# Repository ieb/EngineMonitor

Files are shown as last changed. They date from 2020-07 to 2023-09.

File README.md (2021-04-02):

# EngineMonitor

An engine monitor using a ESP-WROOM-32 board from ebay. It senses 1wire temperature, i2c pressure and temperature (BMP280), and has 2 digial inputs and 4 analogue inputs (ADS1115) for monitoring a typical marine diesel engine. In addition there is a JDY-40 serial RF interface for polling remote sensors.

It emits NMEA2000 messages to a NMEA200 bus, with configuration over Classic Bluetooth serial, saved to flash.

It supports PGN PGN127488 (rapid engine), PGN127489 (engine data), PGN130312 (various temperatures), PGN127508 (battery status), PGN127513 (battery configuration).

Sensors include:

* RPM from W+ terminal of alternator.
* Coolant Temperature
* Oil Pressure
* Fuel Level
* Alternator Voltage
* Alternator Temperature
* Exhaust Temperature
* Engine Room Temperature
* Environment Temperature and Pressure

Other values for the PGNs above are based on interpolation, best guess, fake, where possible. Target engine is a D2-40F, so the code is setup for that engines curves and prop. Most parameters can be changed over the Bluetooth serial CLI.

## RF

Over RF (TBD), Devices based on Arduino Pro Mini, JDY-40, ADS1115 (Arduino ADC not flexible enough). JDY-40s provide a serial 128 RF bands. In each band devices with the same RFID (WirelessID 2bytes) and DVID (Device ID 2bytes). Both the transmitter and reciever channel, RFID and DeviceID must match for packets to be transfered. These are set by AT commands to switch the trancever into that mode. The device will ignore packets that dont match and wont recieve packets that are on a different channel.

JDY-40s were chosen becuase they have a simple serial interface and are relativey low power. BT Classic would have been an alternative but requires pairing and wont work in a mesh and doesnt have the range (top of mast for some sensors). BLE, is just too complex to be bothered with. ZigBee modules are too expensive. NRF24L01+ could have been used, however the interface is SPI. If the JDY-40 cant operate in a mesh then they may need to be replaced with NRF24L01+. For the moment JDY-40 seems the simplest approach, however there is no deal on the JDY-40 RF protocol whereas the NRF24L01+ is detailed https://www.sparkfun.com/datasheets/Components/SMD/nRF24L01Pluss_Preliminary_Product_Specification_v1_0.pdf and has a TCP like RF protocol, and allows upto 6 transmitters to send to a single reciever over parallel data pipes. 

### Communication pattern.

The sensors involved need to provide data periodically, eg every 10s rather than stream continuously at 5Hz. So the simplest mechanism is to use the RFID ID/DeviceID setting in the JDY40. Each node is allocated a ID. On start it waits for a query. The base cycles through each ID requesting data and waiting for a set period for a response before moving to the next device. No blocking operations with communications going via the main loop.

### Protocol

Single line terminated by a NL. Fields comma seperated with the last field being a hex encoded crc16. 
    
      deviceid,datatype,field1,field2,...,fieldn,checksumNL

      device id is the id of the device, 0-255, hex
      datatype defines the fields, 0-255, hex
      field1..n the fields, text formatted.
      checksum a hex crc16 of the whole line excluding , before the checksum.
      NL a new line character.

* Engine Battery voltage, current, temperature, configuration
* Service Battery voltage, current, temperature, configuration

## PCB

The PCB handles power and signal cleaning. 
It is single sided and can easilly be created using basic laser printer+CuCl etching at home, or using a CNC PCB Milling machine (FlatCAM+Candle). 

Power consumption is < 50mA@5V RF sensors consume < 25mA@3.3V

Board used is a ESP-WROOM-32D based board with Wifi and Bluetooth, although Wifi is not used. Available from eBay. https://www.ebay.co.uk/itm/143297558340 30 pin DIL.
Datasheet of the chip https://www.espressif.com/sites/default/files/documentation/esp32-wroom-32d_esp32-wroom-32u_datasheet_en.pdf

Most of the remainder of this readme is notes.

# ESP32 pins

Not all ESP32 pins can be used, but most ESP32 pins can be remapped unlike Arduino boards. 

See PCB Schematic for details of how pins are used.
Pin numbers are the WROOM32 board pin numnbers, names are the pin name of the ESP32 chip.

Digital pulse in 1 -> Pin10/GPIO27
Digital pulse in 2 -> Pin9/GPIO26
RF Chip Enable (low to enable) -> Pin20/D4
RF Serial RX -> PIN21/RX2/GPIO16
RF Serail TX -> Pin22/TX2/GPIO17
RF Serial Enable -> Pin23/D5
CAN RX -> Pin24/D18
CAN TX -> Pin25/D19
1 Wire -> Pin26/D21
i2c SCL -> Pin29/D22
i2c SDA -> Pin30/D23

On the i2c bus is a BMP280 (temp/pressure) and an ADS1115 (4ch 16bit precision ADC) with a pin header for extension.
The Digital pulse is sharpened with a 74HC14 trigger.
CAN Trancever is a MCP2562
RF Serial is a JDY-40 with a Beken BK2461 controller and custom firmware. (2.4 GHz)

ESP32 ADC is non linear and frustrating to use, hence the i2c ACD.

D2 cant be used as its attached to the LED on the board.

GND on 14,17, VIN 5V on 15, 3.3V out on 16 
Other boards may vary but this seems to be a common pattern probably based on a standard Espresif design.

See signalk/SenseESP for details on how to develop.

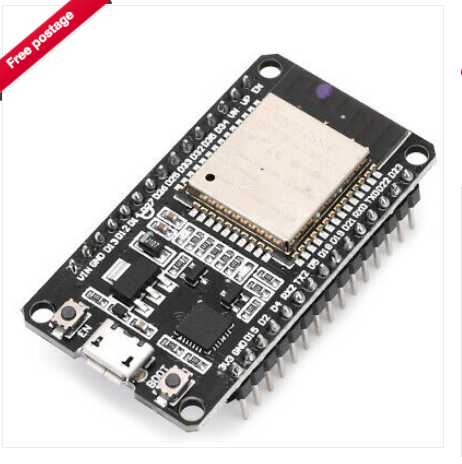
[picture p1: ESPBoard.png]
ESP-WROOM-32D Dev Board


# Connections

The board is intended to monitor the engine, other boards may monitor over the RF link, which avoids having to have many
devices connected to the N2K bus and long wires pulled through tight conduits.

## RF

### Battery Monitoring

Pro Mini with RF board using ACS758xCB at suitable range (eg ACS758ECB-200B-PFF-T, 10mV/A output bidirectional) 1 per battery bank sending data over RF on request, include a 1 wire sensor to sense terminal temperature. Should work as a single board screwed onto the battery terminals.

## 1 Wire

* 3.3v orange marked + board side
* signal white/orange marked nothng
* - green marked - case side

* Alternator Temp 
* Exhaust Temperature 
* Engine Room Temperature
* Service Battery Temperature 

Onewire sensors tend to not be rugged enough to attach directly to a engine block, see below
for coolant temp

## Pulse

* NC Blue, case side, marked 2
* W+ Orange, board side marked 1

## i2c

* BMP280 
   Engine room pressure, less that atmospheric indicates air flow problems.
   Engine room temperature (perhaps, however see 1 wire above)
* ADS1115
   ADC0 = Coolant Temperature Sensor - Blue/Orange - case side, marked C
   ADC1 = Alternator Voltage - White/orange, marked A
   ADC2 = Service battery Voltage - White/brown, marked O (was Oil)
   ADC3 = Fuel Level   - brown - esp32 side, marked F

# NMEA2000 connection

Using an AMP Superseal 4 way connector
Pin 1 +12V - Red
Pin 2 GND - Black
Pin 3 CanL - White
Pin 4 CanH - Blue
Shield GND plane on PCB

GND connected to the NMEA2000 bus may need to be reviewed depending on if there is any voltage differential between NMEA2000 GND and Engine GND due to Charging currents from the alternator. Coolant Temperature will be impacted the most followed by Fuel Level, Oil Pressure and Alternator voltage if there is a significant voltage drop. This will put the NMEA2000 GND +ve to the engine GND increasing the aparant measured coolant temperature and Fuel level when the Alternator is producing high charge output. The GND connection from Engine to Ships GND is short, but not 0R.  

# NMEA2000 PGNs

When connecting the EngineMonitor to a Raymarine MFD it reported errors for messages not expected in Class 50, Propulsion, Function 160 Engine gateway. The suspicion is that non Engine related messages need to be emitted from NMEA2000 device other than the Engine

Engine Monitor Device Class 50 Propulsion, Function 160 Engine gateway. or 140 Engine
127488 (0x1F200) Engine Parameters, Rapid Update 0.1s
127489 (0x1F201) Engine Parameters, Dynamic 0.5s
127505 (0x1F211) Fluid Level 2.5s
130316 (0x1FD0C) Temperature Extended Range

General Temperatures 75/130
130312 (0x1FD08) Temperatures

Atmospheric 85/130
130311 (0x1FD07) Environmental Parameters 10s

Batteries 35/170
127508 (0x1F214) Battery Status

# Related information

This project is targeting a D2-40 engine.

Volvo Penta D2-40 engines like many other Volvo engines have a Mechanical Diesel Interface (MDI) that provides a J1939 interface to the sensors. MDIs are limited in what they sense, and so are probable limited in what they report.

Based on the workshop manual and physical connections the sensors available to the MDI are:

* Supply Voltage
* Coolant Temp, thermistor.
* Oil Pressure Switch
* Flywheel Hall sensor
* Glow plugs (current sensor tbc)
* Starter relay
* Buttons on the control pannel.

Note, there is no ECU on D1,D2 engines as the base engine is a fully mechanical Perkins unit with a mechanical injection pump.

Larger Volvo Penta engines with a full ECU will have many more sensors. A great explanation of J1939 can be found at https://www.csselectronics.com/screen/page/simple-intro-j1939-explained/language/en which is presented on a CAN physical transport.  J1939 is the heavy truck protocol, 250K baud, 29bit PGN. At L7 OSI stack it is J1979 (ISO 15031-5), and at L2 it is CAN (ISO 15765-4). Some commodity ELM327 scanners may be able to read and decode the packets with the correct plugs (eg viecar + CarScanner app).

J1939 is not NMEA2000, as the message structure is different and hence to connect a D2-40 MDI CAN Bus to a NMEA2000 CAN Bus requires a converter. Given how limited the set of sensors is, and how simple the MDI is it may not be worth it for MDI based engines. Volvo Penta Gateways retail at about 300 GBP, the Digital 

# Bench testing

Obviously it is not ideal to bench test with a real engine so its mocked up using a signal generator and a scope. The W+ terminal on the alternator is produced with a 2V sine wave into a 2N2222 switch powered by 14v so that the output is roughly a 14V sine wave.   The temperature sensor is a resistor bridge with the thermistor replaced by a 20 turn pot. 5V supply through a zener powered by 12v trough a 470R. The other voltages are generated with 20 turn 10K pots.

# Tests and todo

* [x] Pulse to Frequency
* [x] ADC measurement on all channels
* [x] Tested on engine
* [x] Fix: make engine port not starboard
* [?] Fix: potential fix of 8 unkown status messages from the device, possibly caused by using 1 device for all messages.
* [x] make device message period configurable
* [x] Shorten rpm send and sample period without loosing precision, currently sampling at 2s, needs to send at 0.2s
* [x] Fix engine on detection.
* [x] Support Bluetooth enable button
* [x] Check 1-wire temperature sensors
* [x] Coolant Temperature conversion
* [x] Alternator pulse verified
* [x] Fuel Level conversion
* [x] Send Fuel Tank level when engine on.
* [x] Install and test.
* [x] Add sensor simulation to test offline without live data.
* [x] Fix engine on reported when not on
* [x] Fix 150c when engine off, so its 0 when off.
* [x] Fix baromiter update too low to Raymarine, lowered to 10s defaul from 60s.
* [x] Fix 8 error messages from engine on init, look like they are 1-8 Unknown Errors, see p113 of the Raymarine LightHouse2 manual, possibly fixed by https://github.com/ttlappalainen/NMEA2000/commit/94c9bd5e1256ad8e4b3b8f7bd3f69339b2645b26
* [x] Reconfigure fuel level measurement, needs some additional wiring to power the fuel sensor from the 5v supply.
* [x] Emit fuel tank when the engine is off.
* [x] Add alarms and configuration expecially for values not supported by displays.
* [x] Make bluetooth touch sensitive
* [x] Install and test2
* [x] Make default thermal sensor match Luna
* [x] Fix engine on bugs
* [x] Removed Touch BT enable and go back to switch to see if it makes i2c initialisation stable, using Touch seems to have introduced instability into the sensors.
* [x] Bench test
* [ ] Install and test3

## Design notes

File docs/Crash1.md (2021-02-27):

# Crash 1

Looks like the interupt handler was not registered correctly with ESP_INTR_FLAG_IRAM enabled, 

https://docs.espressif.com/projects/esp-idf/en/latest/esp32/api-reference/system/intr_alloc.html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

https://docs.espressif.com/projects/esp-idf/en/latest/esp32/api-reference/storage/spi_flash.html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

Writing to Flash requires this. The pulse interuts were called while writing to the flash.

            Guru Meditation Error: Core  1 panic'ed (Cache disabled but cached memory region accessed)
            Core 1 register dump:
            PC      : 0x400d70d8  PS      : 0x00060034  A0      : 0x40084658  A1      : 0x3ffbe7b0  
            A2      : 0x0000001b  A3      : 0x3ffc0988  A4      : 0x00000000  A5      : 0x08000000  
            A6      : 0x3ff42000  A7      : 0x700000bb  A8      : 0x80080f18  A9      : 0xd0000070  
            A10     : 0x00000000  A11     : 0xb0000000  A12     : 0x00000000  A13     : 0x00000000  
            A14     : 0x3ff42000  A15     : 0x700000bb  SAR     : 0x00000011  EXCCAUSE: 0x00000007  
            EXCVADDR: 0x00000000  LBEG    : 0x4000c2e0  LEND    : 0x4000c2f6  LCOUNT  : 0x00000000  
            Core 1 was running in ISR context:
            EPC1    : 0x40062230  EPC2    : 0x00000000  EPC3    : 0x00000000  EPC4    : 0x400d70d8

            Backtrace: 0x400d70d8:0x3ffbe7b0 0x40084655:0x3ffbe7d0 0x4006222d:0x3ffb1be0 0x4008e2ef:0x3ffb1c00 0x4008e326:0x3ffb1c30 0x4008e67c:0x3ffb1c60 0x4008e8d1:0x3ffb1c80 0x400869dd:0x3ffb1cb0 0x40086c54:0x3ffb1cd0 0x400df945:0x3ffb1d20 0x400ddda6:0x3ffb1d40 0x400de121:0x3ffb1d60 0x400dd1f7:0x3ffb1de0 0x400dd796:0x3ffb1e60 0x400dcbbd:0x3ffb1ed0 0x400f38e5:0x3ffb1f10 0x400d74cc:0x3ffb1f40 0x400d75eb:0x3ffb1f70 0x400d1aef:0x3ffb1f90 0x400d9125:0x3ffb1fb0 0x40088a95:0x3ffb1fd0
            #0  0x400d70d8:0x3ffbe7b0 in edgeCountHandler0() at lib/enginemonitor/enginemonitor.cpp:499
            #1  0x40084655:0x3ffbe7d0 in _xt_lowint1 at /home/runner/work/esp32-arduino-lib-builder/esp32-arduino-lib-builder/esp-idf/components/freertos/xtensa_vectors.S:1154
            #2  0x4006222d:0x3ffb1be0 in ?? ??:0
            #3  0x4008e2ef:0x3ffb1c00 in esp_rom_spiflash_read_status at /home/runner/work/esp32-arduino-lib-builder/esp32-arduino-lib-builder/esp-idf/components/spi_flash/spi_flash_rom_patch.c:413
            #4  0x4008e326:0x3ffb1c30 in esp_rom_spiflash_wait_idle at /home/runner/work/esp32-arduino-lib-builder/esp32-arduino-lib-builder/esp-idf/components/spi_flash/spi_flash_rom_patch.c:413
            #5  0x4008e67c:0x3ffb1c60 in esp_rom_spiflash_program_page_internal at /home/runner/work/esp32-arduino-lib-builder/esp32-arduino-lib-builder/esp-idf/components/spi_flash/spi_flash_rom_patch.c:413
            #6  0x4008e8d1:0x3ffb1c80 in esp_rom_spiflash_write at /home/runner/work/esp32-arduino-lib-builder/esp32-arduino-lib-builder/esp-idf/components/spi_flash/spi_flash_rom_patch.c:476
            #7  0x400869dd:0x3ffb1cb0 in spi_flash_write_inner at /home/runner/work/esp32-arduino-lib-builder/esp32-arduino-lib-builder/esp-idf/components/spi_flash/flash_ops.c:266
            #8  0x40086c54:0x3ffb1cd0 in spi_flash_write at /home/runner/work/esp32-arduino-lib-builder/esp32-arduino-lib-builder/esp-idf/components/spi_flash/flash_ops.c:397
            #9  0x400df945:0x3ffb1d20 in nvs::nvs_flash_write(unsigned int, void const*, unsigned int) at /home/runner/work/esp32-arduino-lib-builder/esp32-arduino-lib-builder/esp-idf/components/nvs_flash/src/nvs_ops.cpp:66
            #10 0x400ddda6:0x3ffb1d40 in nvs::Page::writeEntry(nvs::Item const&) at /home/runner/work/esp32-arduino-lib-builder/esp32-arduino-lib-builder/esp-idf/components/nvs_flash/src/nvs_page.cpp:849
            #11 0x400de121:0x3ffb1d60 in nvs::Page::writeItem(unsigned char, nvs::ItemType, char const*, void const*, unsigned int, unsigned char) at /home/runner/work/esp32-arduino-lib-builder/esp32-arduino-lib-builder/esp-idf/components/nvs_flash/src/nvs_page.cpp:849
            #12 0x400dd1f7:0x3ffb1de0 in nvs::Storage::writeMultiPageBlob(unsigned char, char const*, void const*, unsigned int, nvs::VerOffset) at /home/runner/work/esp32-arduino-lib-builder/esp32-arduino-lib-builder/esp-idf/components/nvs_flash/src/nvs_storage.cpp:557
            #13 0x400dd796:0x3ffb1e60 in nvs::Storage::writeItem(unsigned char, nvs::ItemType, char const*, void const*, unsigned int) at /home/runner/work/esp32-arduino-lib-builder/esp32-arduino-lib-builder/esp-idf/components/nvs_flash/src/nvs_storage.cpp:557
            #14 0x400dcbbd:0x3ffb1ed0 in nvs_set_blob at /home/runner/work/esp32-arduino-lib-builder/esp32-arduino-lib-builder/esp-idf/components/nvs_flash/src/nvs_api.cpp:521
            #15 0x400f38e5:0x3ffb1f10 in config::writeStorage(char const*, char const*, void*, unsigned int) at lib/configstorage/configstorage.cpp:40
            #16 0x400d74cc:0x3ffb1f40 in EngineMonitor::saveEngineHours() at lib/enginemonitor/enginemonitor.cpp:499
            #17 0x400d75eb:0x3ffb1f70 in EngineMonitor::readSensors() at lib/enginemonitor/enginemonitor.cpp:499
            #18 0x400d1aef:0x3ffb1f90 in loop() at src/main.cpp:221
            #19 0x400d9125:0x3ffb1fb0 in loopTask(void*) at /Users/ieb/.platformio/packages/framework-arduinoespressif32/cores/esp32/main.cpp:19
            #20 0x40088a95:0x3ffb1fd0 in vPortTaskWrapper at /home/runner/work/esp32-arduino-lib-builder/esp32-arduino-lib-builder/esp-idf/components/freertos/port.c:355 (discriminator 1)

            Rebooting...

Fixed by adding IRAM_ATTR to the handlers and DRAM_ATTR to the variables accessed by the handler both in esp_attr.h

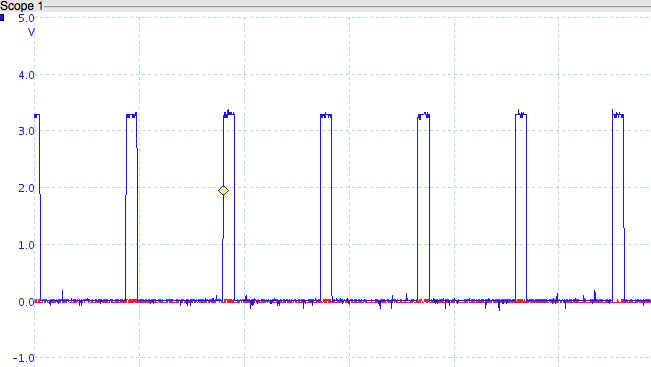
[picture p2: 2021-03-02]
docs/PulseOutputFrom74HC14.png

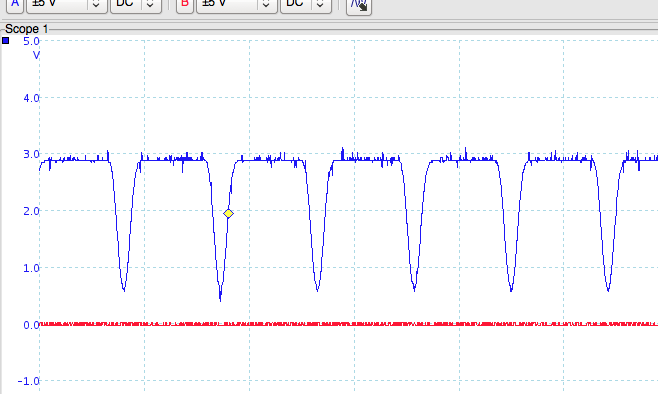
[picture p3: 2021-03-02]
docs/PulseInputTo74HC14.png

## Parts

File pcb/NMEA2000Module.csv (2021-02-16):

Id | Designator | Package | Quantity | Designation | Supplier and ref
1 | U2 | DIP-30_1_ELL | 1 | ESP32Dev
2 | C1,C3 | C_0805_HandSoldering | 2 | 100nF
3 | C2,C4 | C_0805_HandSoldering | 2 | 50nF
4 | C5,C6,C7,C8 | C_0805_HandSoldering | 4 | 10nF
5 | D1 | Resistor_Horizontal_RM7mm | 1 | DIODE
6 | IC1 | DIP-8_W7.62mm_LongPads | 1 | MCP2562FD
7 | P3 | Pin_Header_Straight_1x02_Pitch2.54mm | 1 | TERM_R
8 | R1,R3,R6,R8,R10,R13 | R_0805_HandSoldering | 6 | 10K
9 | R2,R4 | R_0805_HandSoldering | 2 | 3K3
10 | R7,R9,R11,R14 | R_0805_HandSoldering | 4 | 2K2
11 | R12,R15,R16 | R_0805_HandSoldering | 3 | 4K7
12 | U1 | DIP-14_W7.62mm_LongPads | 1 | 74HC14
13 | U3 | JDY-40-TH | 1 | JDY40
14 | R17 | R_0805_HandSoldering | 1 | 120R
15 | K1 | Pin_Header_Straight_1x03_Pitch2.54mm | 1 | 1W1
16 | P1 | Pin_Header_Straight_1x02_Pitch2.54mm | 1 | PULSE_IN
17 | P4 | Pin_Header_Straight_1x04_Pitch2.54mm | 1 | CAN
18 | P7 | Pin_Header_Straight_1x04_Pitch2.54mm | 1 | I2C1
19 | P9 | Pin_Header_Straight_1x04_Pitch2.54mm | 1 | ANALOG IN
20 | U5 | BMP280 | 1 | BMP280
21 | U6 | ADS1115 | 1 | ADS1115
22 | U4 | DC-DC-Converter | 1 | DCDCConverter

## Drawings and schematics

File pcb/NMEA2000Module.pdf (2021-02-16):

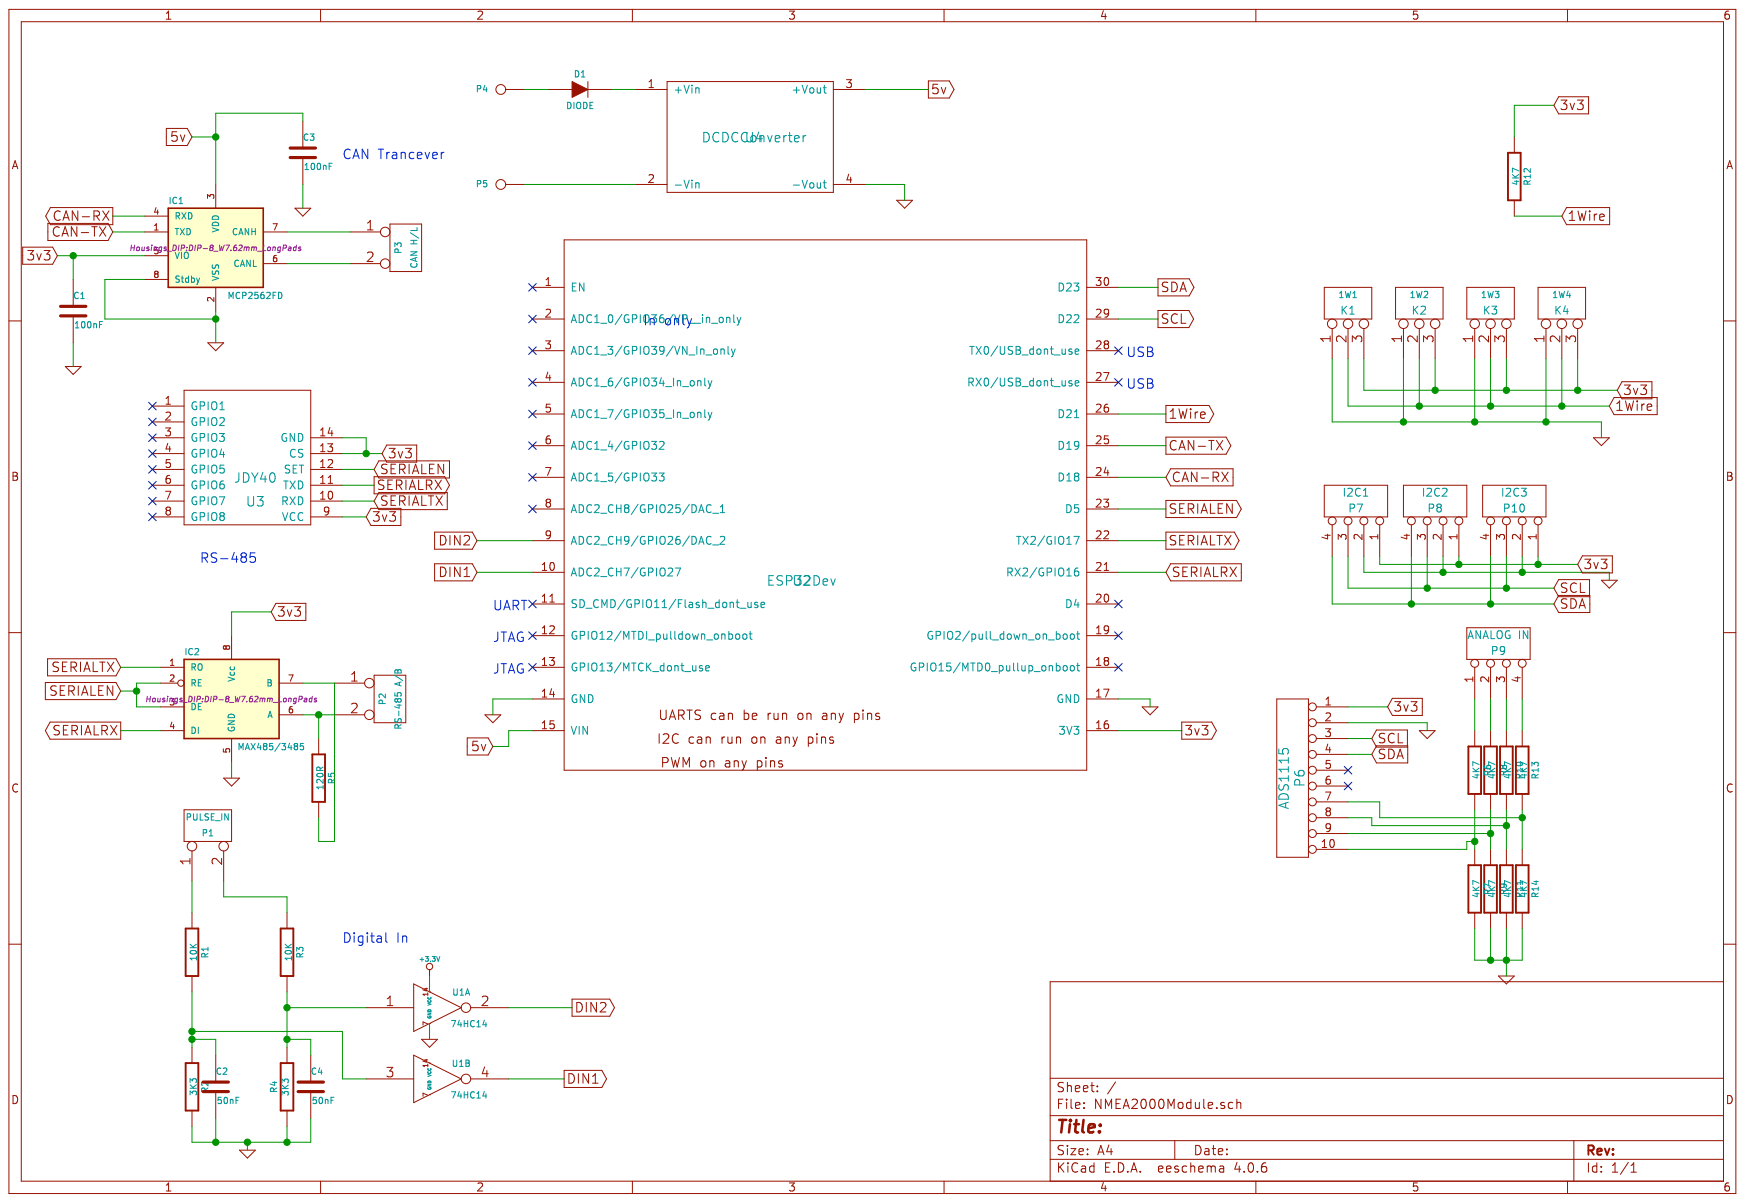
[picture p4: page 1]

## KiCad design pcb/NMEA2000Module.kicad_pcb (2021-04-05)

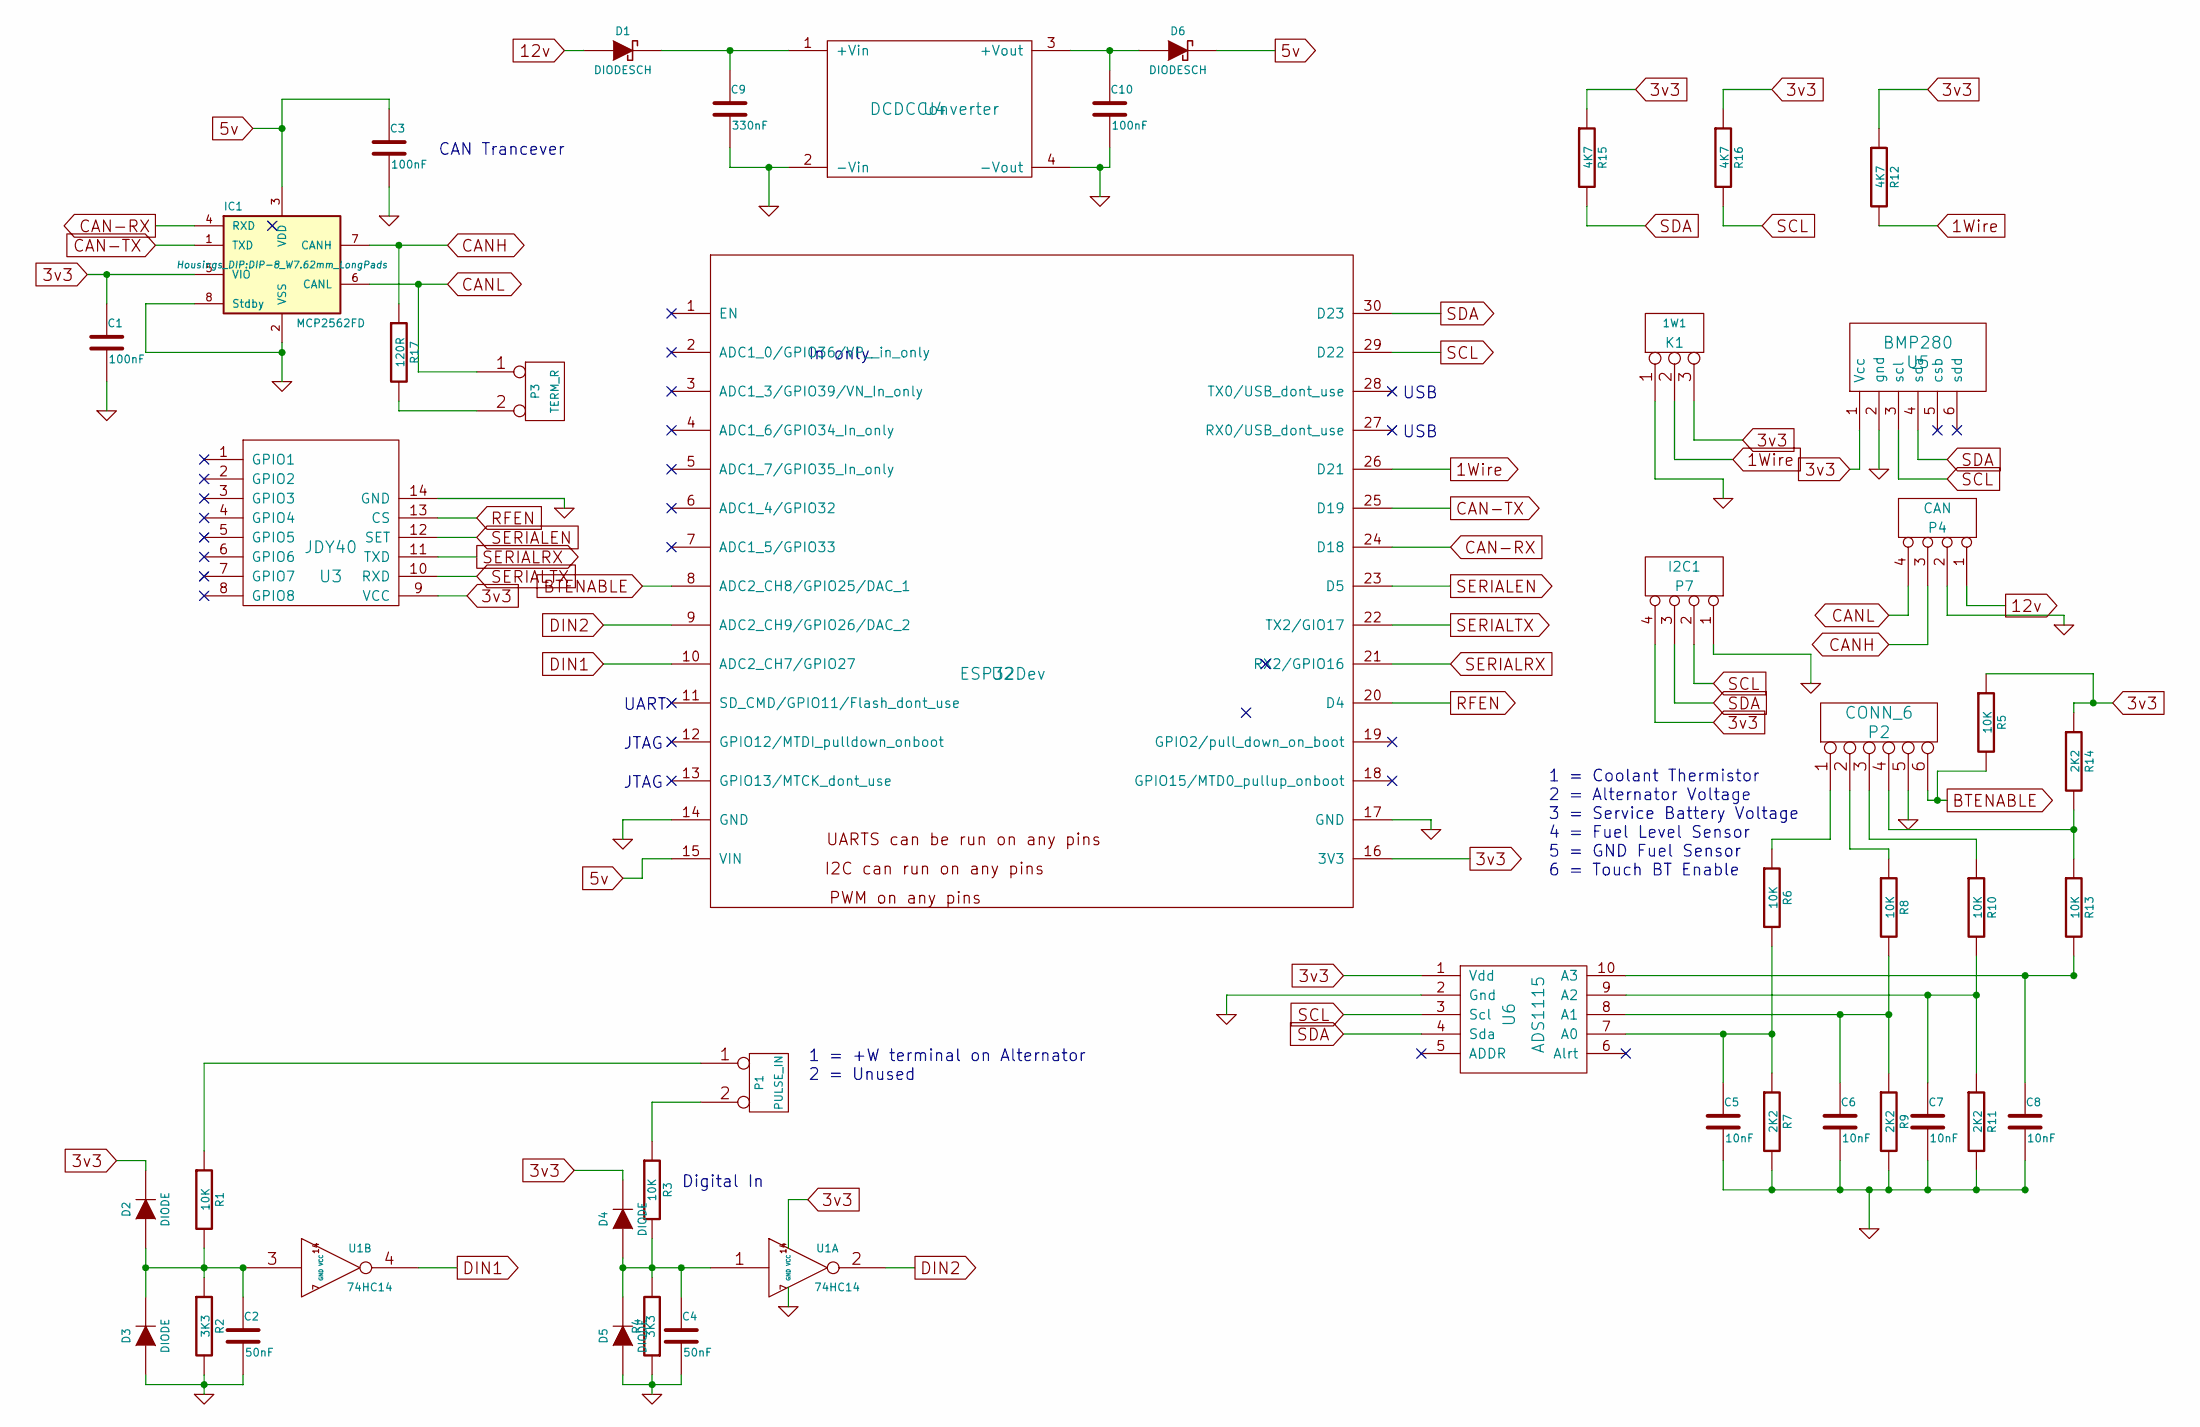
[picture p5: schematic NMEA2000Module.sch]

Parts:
C1, C3, C10: 100nF; C_0805_HandSoldering
C2, C4: 50nF; C_0805_HandSoldering
C5, C6, C7, C8: 10nF; C_0805_HandSoldering
C9: 330nF; C_0805_HandSoldering
D1, D6: DIODESCH; Resistor_Horizontal_RM7mm
D2, D3, D4, D5: DIODE; SOT-23
IC1: MCP2562FD; DIP-8_W7.62mm_LongPads
K1: 1W1; Pin_Header_Straight_1x03_Pitch2.54mm
P1: PULSE_IN; Pin_Header_Straight_1x02_Pitch2.54mm
P2: CONN_6; Pin_Header_Straight_1x06_Pitch2.54mm
P3: TERM_R; Pin_Header_Straight_1x02_Pitch2.54mm
P4: CAN; Pin_Header_Straight_1x04_Pitch2.54mm
P7: I2C1; Pin_Header_Straight_1x04_Pitch2.54mm
R1, R3, R5, R6, R8, R10, R13: 10K; R_0805_HandSoldering
R2, R4: 3K3; R_0805_HandSoldering
R7, R9, R11, R14: 2K2; R_0805_HandSoldering
R12, R15, R16: 4K7; R_0805_HandSoldering
R17: 120R; R_0805_HandSoldering
U1: 74HC14; DIP-14_W7.62mm_LongPads
U2: ESP32Dev; DIP-30_1_ELL
U3: JDY40; JDY-40-TH
U4: DCDCConverter; DC-DC-Converter
U5: BMP280
U6: ADS1115

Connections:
1Wire: K1.2 (PM), R12.2, U2.26 (D21)
3v3: C1.1, D2.2 (K), D4.2 (K), IC1.5 (VIO), K1.3, P7.4, R5.1, R12.1, R14.1, R15.1, R16.1, U1.14 (VCC), U2.16 (3V3), U3.9 (VCC), U5.1 (Vcc), U6.1 (Vdd)
5v: C3.1, D6.2 (K), IC1.3 (VDD), U2.15 (VIN)
12v: D1.1 (A), P4.1
BTENABLE: P2.6, R5.2, U2.8 (ADC2_CH8/GPIO25/DAC_1)
CAN-RX: IC1.4 (RXD), U2.24 (D18)
CAN-TX: IC1.1 (TXD), U2.25 (D19)
CANH: IC1.7 (CANH), P4.3, R17.1
CANL: IC1.6 (CANL), P3.1, P4.4
DIN1: U1.4, U2.10 (ADC2_CH7/GPIO27)
DIN2: U1.2, U2.9 (ADC2_CH9/GPIO26/DAC_2)
GND: C1.2, C2.2, C3.2, C4.2, C5.2, C6.2, C7.2, C8.2, C9.2, C10.2, D3.1 (A), D5.1 (A), IC1.2 (VSS), IC1.8 (Stdby), K1.1, P2.5, P4.2, P7.1, R2.2, R4.1, R7.2, R9.2, R11.2, U1.7 (GND), U2.14 (GND), U2.17 (GND), U3.14 (GND), U4.2 (-Vin), U4.4 (-Vout), U5.2 (gnd), U6.2 (Gnd)
unnamed: C2.1, D2.1 (A), D3.2 (K), R1.2, R2.1, U1.3
unnamed: C4.1, D4.1 (A), D5.2 (K), R3.2, R4.2, U1.1
unnamed: C5.1, R6.2, R7.1, U6.7 (A0)
unnamed: C6.1, R8.2, R9.1, U6.8 (A1)
unnamed: C7.1, R10.2, R11.1, U6.9 (A2)
unnamed: C8.1, R13.2, U6.10 (A3)
unnamed: C9.1, D1.2 (K), U4.1 (+Vin)
unnamed: C10.1, D6.1 (A), U4.3 (+Vout)
unnamed: P1.1, R1.1
unnamed: P1.2 (PM), R3.1
unnamed: P2.1, R6.1
unnamed: P2.2, R8.1
unnamed: P2.3, R10.1
unnamed: P2.4, R13.1, R14.2
unnamed: P3.2 (PM), R17.2
RFEN: U2.20 (D4), U3.13 (CS)
SCL: P7.2, R16.2, U2.29 (D22), U5.3 (scl), U6.3 (Scl)
SDA: P7.3, R15.2, U2.30 (D23), U5.4 (sda), U6.4 (Sda)
SERIALEN: U2.23 (D5), U3.12 (SET)
SERIALRX: U2.21 (RX2/GPIO16), U3.11 (TXD)
SERIALTX: U2.22 (TX2/GIO17), U3.10 (RXD)

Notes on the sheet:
CAN Trancever
Digital In
JTAG
USB
UART
In only
1 = Coolant Thermistor 2 = Alternator Voltage 3 = Service Battery Voltage 4 = Fuel Level Sensor 5 = GND Fuel Sensor 6 = Touch BT Enable
1 = +W terminal on Alternator 2 = Unused

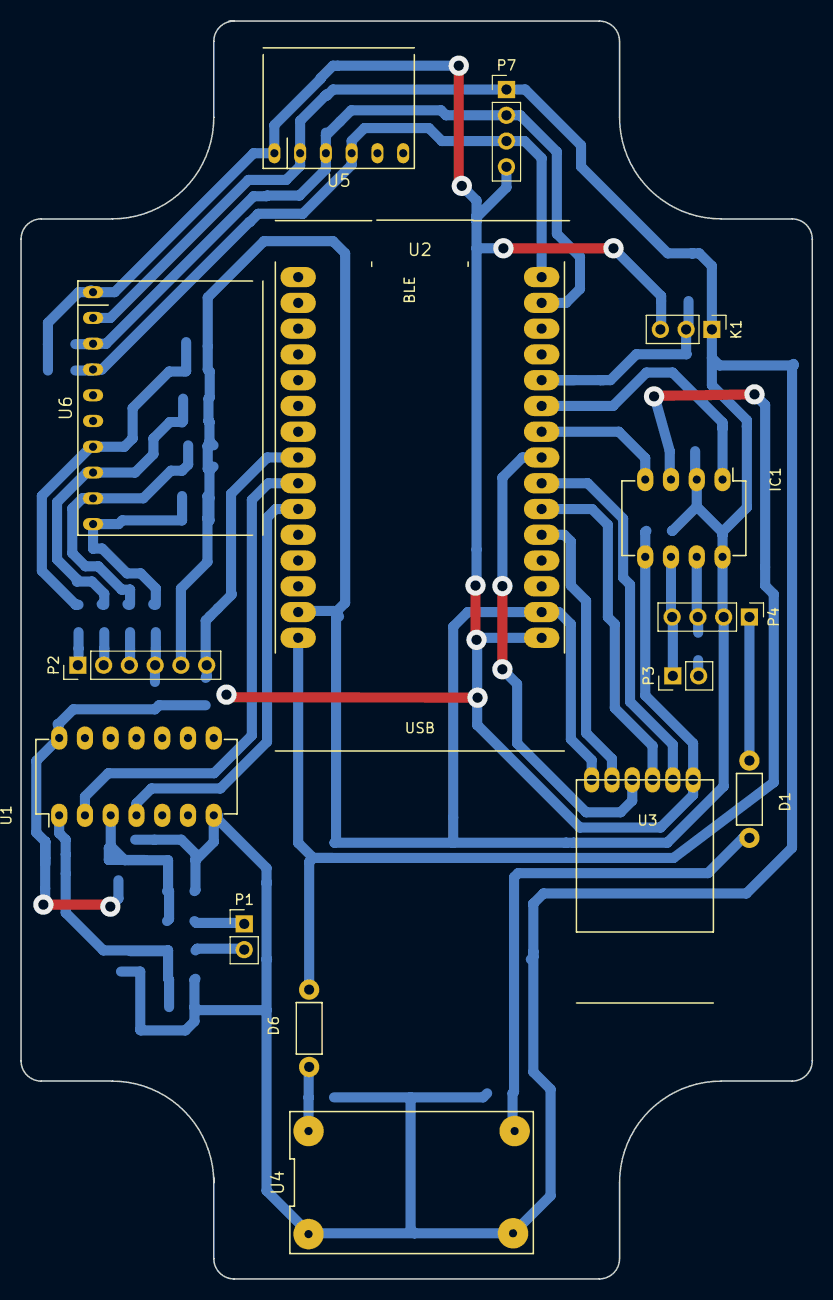
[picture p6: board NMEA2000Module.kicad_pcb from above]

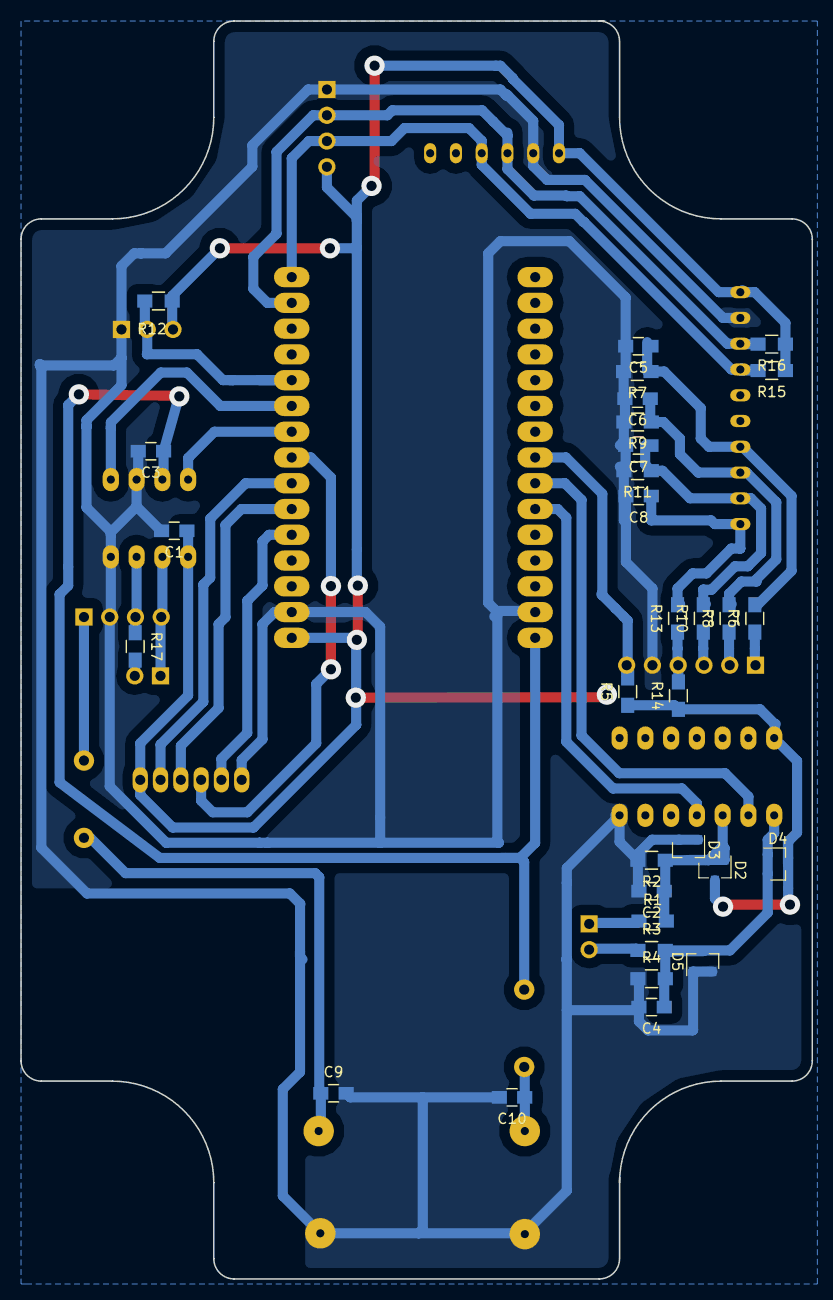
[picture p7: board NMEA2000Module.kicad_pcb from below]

Board: 2 copper layers, 78.0 x 124.0 mm, 46 parts (31 on the bottom side), 33 nets.

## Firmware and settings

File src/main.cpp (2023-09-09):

#include <Arduino.h>

#include <Adafruit_BMP280.h>


//#define SERIAL_DEBUG_DISABLED
// #define DEBUG_NMEA2000 1

#define ESP32_CAN_TX_PIN GPIO_NUM_19
#define ESP32_CAN_RX_PIN GPIO_NUM_18

#define ONEWIRE_PIN GPIO_NUM_21
#define SCL_PIN GPIO_NUM_22
#define SDA_PIN GPIO_NUM_23
#define DATAEN_PIN GPIO_NUM_4 
#define RF_RX  GPIO_NUM_16
#define RF_TX  GPIO_NUM_17
#define BT_INDICATOR_PIN GPIO_NUM_2
#define BT_ENABLE_PIN GPIO_NUM_25



#include <NMEA2000_esp32.h>
#include <NMEA2000_CAN.h> 
#include <N2kMessages.h>


#include <enginemonitor.h>
#include <engineconfig.h>

#define BLUETOOTHCLASSIC 1
#ifdef BLUETOOTHCLASSIC
#include <BlueToothSerial.h>
BluetoothSerial SerialBT;
#define SerialIO SerialBT
#else
#define SerialIO Serial
#endif

const unsigned long TransmitMessagesEngine[] PROGMEM={
  127488L, // Rapid engine ideally 0.1s
  127489L, // Dynamic engine 0.5s
  127505L, // Tank Level 2.5s
  130316L, // Extended Temperature 2.5s
  0};
const unsigned long TransmitMessagesTemperature[] PROGMEM={
  130312L, // temperature
  0};
const unsigned long TransmitMessagesAtmospheric[] PROGMEM={
  130311L, // environment
  0};
const unsigned long TransmitMessagesBatteries[] PROGMEM={
  127508L, // Battery status 5s
  0};




OneWire oneWire(ONEWIRE_PIN);
EngineMonitor engineMonitor(&oneWire,  &SerialIO);
EngineConfig engineConfig(&engineMonitor, &SerialIO);
Adafruit_BMP280 bmp; // I2C
bool hasBMP280 = true;

#define INPUT_BUFFER_SIZE 1024
char inputBuffer[INPUT_BUFFER_SIZE];


#define NMEA2000_DEV_ENGINE      0
#define NMEA2000_DEV_TEMPERATURE 1
#define NMEA2000_DEV_ATMOSPHERIC 2
#define NMEA2000_DEV_BATTERIES   3



volatile DRAM_ATTR int enableBluetoothPressed = 0;

void IRAM_ATTR handleBluetoothEnable() {
  enableBluetoothPressed = true;
}


int blueToothRunning = 0;


void StopBluetooth() {
#ifdef BLUETOOTHCLASSIC      
  if ( blueToothRunning ) {
    Serial.println("BT off");
    SerialBT.end();
    digitalWrite(BT_INDICATOR_PIN, LOW); 
    blueToothRunning = false;
  }
#endif
}

void CheckBluetooth() {
#ifdef BLUETOOTHCLASSIC   
  if ( !blueToothRunning ) {
    if ( enableBluetoothPressed ) {
      Serial.println("BT on" );
      SerialBT.begin("EngineMonitor"); 
      digitalWrite(BT_INDICATOR_PIN, HIGH); 
      blueToothRunning = true;
      enableBluetoothPressed = false;
    }
  } else {
    if ( enableBluetoothPressed ) {
      Serial.println("BT off");
      SerialBT.end();
      digitalWrite(BT_INDICATOR_PIN, LOW); 
      blueToothRunning = false;
      enableBluetoothPressed = false;
    }
  }
#endif
}

void setup() {

  
#ifdef BLUETOOTHCLASSIC  
  pinMode(BT_ENABLE_PIN, INPUT);
  attachInterrupt(digitalPinToInterrupt(BT_ENABLE_PIN), handleBluetoothEnable, FALLING);
  pinMode(BT_INDICATOR_PIN, OUTPUT);
  digitalWrite(BT_INDICATOR_PIN, LOW); 
  CheckBluetooth();
#else 
#endif
  Serial.begin(115200);

  Wire.begin(SDA_PIN, SCL_PIN);
  Serial.println("Starting sensors");


  hasBMP280 = true;
  if (!bmp.begin(0x76)) {
    if (!bmp.begin(0x77)) {
      Serial.println(F("Could not find a valid BMP280 sensor, check wiring. true 0x76 and 0x77"));
      hasBMP280 = false;
    }
  }
  if ( hasBMP280 ) {
    /* Default settings from datasheet. */
    bmp.setSampling(Adafruit_BMP280::MODE_NORMAL,     /* Operating Mode. */
                    Adafruit_BMP280::SAMPLING_X2,     /* Temp. oversampling */
                    Adafruit_BMP280::SAMPLING_X16,    /* Pressure oversampling */
                    Adafruit_BMP280::FILTER_X16,      /* Filtering. */
                    Adafruit_BMP280::STANDBY_MS_500); /* Standby time. */

  }

  Serial.println("Sensors Started");
  Serial.println("Starting Engine interface");

  engineConfig.begin();
  engineConfig.dump();
  engineMonitor.begin();  

  Serial.println("Starting NMEA2000");

  NMEA2000.SetDeviceCount(4);

  // Setup NMEA2000
  // Set Product information
  NMEA2000.SetProductInformation("00000003", // Manufacturer's Model serial code
                                 100, // Manufacturer's product code
                                 "Engine Monitor",  // Manufacturer's Model ID
                                 "1.1.0.22 (2021-02-10)",  // Manufacturer's Software version code
                                 "1.1.0.0 (2021-02-10)", // Manufacturer's Model version
                                 0xff, // load equivalency - use default
                                 0xffff, // NMEA 2000 version - use default
                                 0xff, // Sertification level - use default
                                 NMEA2000_DEV_ENGINE
                                 );
  NMEA2000.SetProductInformation("00000004", // Manufacturer's Model serial code
                                 100, // Manufacturer's product code
                                 "Temperature Monitor",  // Manufacturer's Model ID
                                 "1.1.0.22 (2021-02-10)",  // Manufacturer's Software version code
                                 "1.1.0.0 (2021-02-10)", // Manufacturer's Model version
                                 0xff, // load equivalency - use default
                                 0xffff, // NMEA 2000 version - use default
                                 0xff, // Sertification level - use default
                                 NMEA2000_DEV_TEMPERATURE
                                 );
  NMEA2000.SetProductInformation("00000005", // Manufacturer's Model serial code
                                 100, // Manufacturer's product code
                                 "Environment Monitor",  // Manufacturer's Model ID
                                 "1.1.0.22 (2021-02-10)",  // Manufacturer's Software version code
                                 "1.1.0.0 (2021-02-10)", // Manufacturer's Model version
                                 0xff, // load equivalency - use default
                                 0xffff, // NMEA 2000 version - use default
                                 0xff, // Sertification level - use default
                                 NMEA2000_DEV_ATMOSPHERIC
                                 );
  NMEA2000.SetProductInformation("00000006", // Manufacturer's Model serial code
                                 100, // Manufacturer's product code
                                 "Battery Monitor",  // Manufacturer's Model ID
                                 "1.1.0.22 (2021-02-10)",  // Manufacturer's Software version code
                                 "1.1.0.0 (2021-02-10)", // Manufacturer's Model version
                                 0xff, // load equivalency - use default
                                 0xffff, // NMEA 2000 version - use default
                                 0xff, // Sertification level - use default
                                 NMEA2000_DEV_BATTERIES
                                 );
  // Set device information
  NMEA2000.SetDeviceInformation(3, // Unique number. Use e.g. Serial number.
                                160, // Device function=Engine Gateway. See codes on http://www.nmea.org/Assets/20120726%20nmea%202000%20class%20&%20function%20codes%20v%202.00.pdf
                                50, // Device class=Propulsion. See codes on  http://www.nmea.org/Assets/20120726%20nmea%202000%20class%20&%20function%20codes%20v%202.00.pdf
                                2085, // Just choosen free from code list on http://www.nmea.org/Assets/20121020%20nmea%202000%20registration%20list.pdf                               
                                4, // Marine
                                NMEA2000_DEV_ENGINE
                                );
  NMEA2000.SetDeviceInformation(4, // Unique number. Use e.g. Serial number.
                                130, // Device function=Engine Gateway. See codes on http://www.nmea.org/Assets/20120726%20nmea%202000%20class%20&%20function%20codes%20v%202.00.pdf
                                75, // Device class=Propulsion. See codes on  http://www.nmea.org/Assets/20120726%20nmea%202000%20class%20&%20function%20codes%20v%202.00.pdf
                                2085, // Just choosen free from code list on http://www.nmea.org/Assets/20121020%20nmea%202000%20registration%20list.pdf                               
                                4, // Marine
                                NMEA2000_DEV_TEMPERATURE
                                );
  NMEA2000.SetDeviceInformation(5, // Unique number. Use e.g. Serial number.
                                130, // Device function=Engine Gateway. See codes on http://www.nmea.org/Assets/20120726%20nmea%202000%20class%20&%20function%20codes%20v%202.00.pdf
                                85, // Device class=Propulsion. See codes on  http://www.nmea.org/Assets/20120726%20nmea%202000%20class%20&%20function%20codes%20v%202.00.pdf
                                2085, // Just choosen free from code list on http://www.nmea.org/Assets/20121020%20nmea%202000%20registration%20list.pdf                               
                                4, // Marine
                                NMEA2000_DEV_ATMOSPHERIC
                                );
  NMEA2000.SetDeviceInformation(5, // Unique number. Use e.g. Serial number.
                                170, // Device function=Engine Gateway. See codes on http://www.nmea.org/Assets/20120726%20nmea%202000%20class%20&%20function%20codes%20v%202.00.pdf
                                35, // Device class=Propulsion. See codes on  http://www.nmea.org/Assets/20120726%20nmea%202000%20class%20&%20function%20codes%20v%202.00.pdf
                                2085, // Just choosen free from code list on http://www.nmea.org/Assets/20121020%20nmea%202000%20registration%20list.pdf                               
                                4, // Marine
                                NMEA2000_DEV_BATTERIES
                                );

  // debugging with no chips connected.
#ifdef DEBUG_NMEA2000
  NMEA2000.SetForwardStream(&SerialIO);
  NMEA2000.SetDebugMode(tNMEA2000::dm_ClearText);
  NMEA2000.SetForwardType(tNMEA2000::fwdt_Text); 
  NMEA2000.SetDebugMode(tNMEA2000::dm_ClearText); // Uncomment this, so you can test code without CAN bus chips on Arduino Mega
#endif

  // this is a node, we are not that interested in other traffic on the bus.
  NMEA2000.SetMode(tNMEA2000::N2km_NodeOnly,23);
  NMEA2000.EnableForward(false);
  NMEA2000.ExtendTransmitMessages(TransmitMessagesEngine,NMEA2000_DEV_ENGINE);
  NMEA2000.ExtendTransmitMessages(TransmitMessagesTemperature,NMEA2000_DEV_TEMPERATURE);
  NMEA2000.ExtendTransmitMessages(TransmitMessagesAtmospheric,NMEA2000_DEV_ATMOSPHERIC);
  NMEA2000.ExtendTransmitMessages(TransmitMessagesBatteries,NMEA2000_DEV_BATTERIES);
  NMEA2000.Open();

  

  Serial.println("running, touch pin 33 to enable BT");
  
}

// todo, configuration.


void SendRapidEngineData() {
  static unsigned long RapidEngineUpdated=millis();
  tN2kMsg N2kMsg;
  unsigned long period = engineMonitor.getRapidEngineUpdatePeriod();
  if ( period != 0 && millis()-RapidEngineUpdated > period ) {
    if ( engineMonitor.isEngineOn() ) {  
      double rpm = engineMonitor.getFlyWheelRPM();
      if ( engineConfig.isMonitoringEnabled() ) {
        SerialIO.printf("RPM %f\n",rpm);
      }
      // PGN127488
      SetN2kEngineParamRapid(N2kMsg, 0, rpm);
      NMEA2000.SendMsg(N2kMsg, NMEA2000_DEV_ENGINE);
    }
  
    RapidEngineUpdated = millis();
  }
}

void SendEngineData() {
  static unsigned long EngineUpdated=millis();
  tN2kMsg N2kMsg;

  unsigned long period = engineMonitor.getEngineUpdatePeriod();
  if ( period != 0 && millis()-EngineUpdated > period ) {
    if ( engineMonitor.isEngineOn() ) {  

      // PGN127489
      double temperature = engineMonitor.getCoolantTemperature();
      double alternatorVoltage = engineMonitor.getAlternatorVoltage();
      double engineHours = engineMonitor.getEngineHours();

      if ( engineConfig.isMonitoringEnabled() ) {
        SerialIO.printf("Engine Params1 t=%f, av=%f, eh=%f\n",
          temperature, alternatorVoltage, engineHours);
      }

      /*

  inline void SetN2kEngineDynamicParam(tN2kMsg &N2kMsg, unsigned char EngineInstance, double EngineOilPress, double EngineOilTemp, double EngineCoolantTemp, double AltenatorVoltage,
                        double FuelRate, double EngineHours, double EngineCoolantPress=N2kDoubleNA, double EngineFuelPress=N2kDoubleNA,
                        int8_t EngineLoad=N2kInt8NA, int8_t EngineTorque=N2kInt8NA,
                        tN2kEngineDiscreteStatus1 Status1=0, tN2kEngineDiscreteStatus2 Status2=0) {
                          */
      SetN2kEngineDynamicParam(N2kMsg, 0, N2kDoubleNA, N2kDoubleNA, CToKelvin(temperature), alternatorVoltage,
                        N2kDoubleNA, engineHours, N2kDoubleNA, N2kDoubleNA, N2kInt8NA, N2kInt8NA,0,0);

      NMEA2000.SendMsg(N2kMsg, NMEA2000_DEV_ENGINE);
    }

    // always send the fuel level data.
    SetN2kFluidLevel(N2kMsg,0,N2kft_Fuel,engineMonitor.getFuelTankLevel(),engineMonitor.getFuelTankCapacity());
    NMEA2000.SendMsg(N2kMsg, NMEA2000_DEV_ENGINE);

    EngineUpdated=millis();
  }
}




void SendTemperatureData() {
  static unsigned long TemperatureUpdated=millis();
  tN2kMsg N2kMsg;

  unsigned long period = engineMonitor.getTemperatureUpdatePeriod();
  if ( period != 0 && millis()-TemperatureUpdated > period ) {
    // PGN130312
    if ( engineConfig.isMonitoringEnabled() ) {
      SerialIO.printf("Temperature er=%f, eg=%f, at=%f\n",
        engineMonitor.getEngineRoomTemperature(), engineMonitor.getExhaustTemperature(), engineMonitor.getAlternatorTemperature());
    }

    SetN2kTemperature(N2kMsg, 0, 0, N2kts_EngineRoomTemperature, CToKelvin(engineMonitor.getEngineRoomTemperature()));
    NMEA2000.SendMsg(N2kMsg, NMEA2000_DEV_TEMPERATURE);
    SetN2kTemperature(N2kMsg, 1, 1, N2kts_ExhaustGasTemperature, CToKelvin(engineMonitor.getExhaustTemperature()));
    NMEA2000.SendMsg(N2kMsg, NMEA2000_DEV_TEMPERATURE);
    SetN2kTemperature(N2kMsg, 2, 2, N2kts_LiveWellTemperature, CToKelvin(engineMonitor.getAlternatorTemperature()));
    NMEA2000.SendMsg(N2kMsg, NMEA2000_DEV_TEMPERATURE);
    TemperatureUpdated=millis();
  }
}


void SendVoltages() {
  static unsigned long VoltageUpdated=millis();
  tN2kMsg N2kMsg;

  unsigned long period = engineMonitor.getVoltageUpdatePeriod();
  if ( period != 0 && millis() - VoltageUpdated > period ) {

    // Battery Status PGN127508
    if ( engineConfig.isMonitoringEnabled() ) {
      SerialIO.printf("Voltages sb=%f, av=%f\n",
        engineMonitor.getServiceBatteryVoltage(), engineMonitor.getAlternatorVoltage());
    }
    
    SetN2kDCBatStatus(N2kMsg,0, engineMonitor.getServiceBatteryVoltage(), N2kDoubleNA, CToKelvin(engineMonitor.getServiceBatteryTemperature()), 0);
    NMEA2000.SendMsg(N2kMsg, NMEA2000_DEV_BATTERIES);
    // send the Alternator information as if it was a 3rd battery, becuase there is no other way.
    SetN2kDCBatStatus(N2kMsg,1, engineMonitor.getAlternatorVoltage(), N2kDoubleNA, CToKelvin(engineMonitor.getAlternatorTemperature()), 1);
    NMEA2000.SendMsg(N2kMsg, NMEA2000_DEV_BATTERIES);

    // Battery Configuration PGN127513
//    SetN2kBatConf(N2kMsg,1,N2kDCbt_Flooded,N2kDCES_Unavailable,N2kDCbnv_12v,N2kDCbc_LeadAcid,AhToCoulomb(55),53,1.251,75);
//    NMEA2000.SendMsg(N2kMsg);
//    SetN2kBatConf(N2kMsg,2,N2kDCbt_AGM,N2kDCES_Unavailable,N2kDCbnv_12v,N2kDCbc_LeadAcid,AhToCoulomb(330),53,1.251,75);
//    NMEA2000.SendMsg(N2kMsg);
    VoltageUpdated=millis();
  }
}


void SendEnvironment() {
  static unsigned long EnvironmentUpdated=millis();
  if ( hasBMP280 ) {

    tN2kMsg N2kMsg;

    unsigned long period = engineMonitor.getEnvironmentUpdatePeriod();
    if ( period != 0 && millis() - EnvironmentUpdated > period ) {

        double temperature = bmp.readTemperature();
        double pressure =  bmp.readPressure();

      if ( engineConfig.isMonitoringEnabled() ) {
        SerialIO.printf("Environment t=%f, p=%f\n",
          temperature, pressure);
      }

      // PGN130311
      SetN2kEnvironmentalParameters(N2kMsg,4,
        tN2kTempSource::N2kts_InsideTemperature,
        CToKelvin(temperature),N2khs_Undef,N2kDoubleNA,pressure);
      NMEA2000.SendMsg(N2kMsg, NMEA2000_DEV_ATMOSPHERIC);

      EnvironmentUpdated=millis();
        
    }
  }

}

void DumpStatus() {
    SerialIO.printf("Has BMP280              = %d\n", hasBMP280);
    SerialIO.printf("Engine Powered up       = %d\n", engineMonitor.isEngineOn());
    SerialIO.printf("Engine Running          = %d\n", engineMonitor.isEngineRunning());
    SerialIO.printf("RPM                     = %f\n", engineMonitor.getFlyWheelRPM());
    SerialIO.printf("Coolant Temperature     = %f C\n", engineMonitor.getCoolantTemperature());
    SerialIO.printf("Fuel Tank Level         = %f %%\n", engineMonitor.getFuelTankLevel());
    SerialIO.printf("Fuel Tank Level         = %f l\n", engineMonitor.getFuelTankLevel()*engineMonitor.getFuelTankCapacity()/100.0);
    SerialIO.printf("Fuel Tank Capacity      = %f l\n", engineMonitor.getFuelTankCapacity());
    SerialIO.printf("Alternator Voltage      = %f V\n", engineMonitor.getAlternatorVoltage());
    SerialIO.printf("Service Battery Voltage = %f V\n", engineMonitor.getServiceBatteryVoltage());
    SerialIO.printf("Engine Hours            = %f h\n", engineMonitor.getEngineHours());
    SerialIO.printf("Engine Room Temperature = %f C\n", engineMonitor.getEngineRoomTemperature());
    SerialIO.printf("Exhaust Temperature     = %f C\n", engineMonitor.getExhaustTemperature());
    SerialIO.printf("Alternator Temperature  = %f C\n", engineMonitor.getAlternatorTemperature());
    SerialIO.printf("Service Battery Temp    = %f C\n", engineMonitor.getServiceBatteryTemperature());
    SerialIO.printf("Inside Temperature      = %f C\n", bmp.readTemperature());
    SerialIO.printf("Inside Pressure         = %f Pa\n", bmp.readPressure());
    tN2kEngineDiscreteStatus1 status1 = engineMonitor.getEngineStatus1();
    tN2kEngineDiscreteStatus2 status2 = engineMonitor.getEngineStatus2();

    SerialIO.print("Alarms: ");
    if ( status1.Bits.CheckEngine ) SerialIO.print("CheckEngine ");
    if ( status1.Bits.OverTemperature ) SerialIO.print("OverTemperature ");
    if ( status1.Bits.LowOilPressure ) SerialIO.print("LowOilPressure ");
    if ( status1.Bits.LowOilLevel ) SerialIO.print("LowOilLevel ");
    if ( status1.Bits.LowFuelPressure ) SerialIO.print("LowFuelPressure ");
    if ( status1.Bits.LowSystemVoltage ) SerialIO.print("LowSystemVoltage ");
    if ( status1.Bits.LowCoolantLevel ) SerialIO.print("LowCoolantLevel ");
    if ( status1.Bits.WaterFlow ) SerialIO.print("WaterFlow ");
    if ( status1.Bits.WaterInFuel ) SerialIO.print("WaterInFuel ");
    if ( status1.Bits.ChargeIndicator ) SerialIO.print("ChargeIndicator ");
    if ( status1.Bits.PreheatIndicator ) SerialIO.print("PreheatIndicator ");
    if ( status1.Bits.HighBoostPressure ) SerialIO.print("HighBoostPressure ");
    if ( status1.Bits.RevLimitExceeded ) SerialIO.print("RevLimitExceeded ");
    if ( status1.Bits.EGRSystem ) SerialIO.print("EGRSystem ");
    if ( status1.Bits.ThrottlePositionSensor ) SerialIO.print("ThrottlePositionSensor ");
    if ( status1.Bits.EngineEmergencyStopMode ) SerialIO.print("EngineEmergencyStopMode ");
    if ( status1.Bits.HighBoostPressure ) SerialIO.print("HighBoostPressure ");
    if ( status2.Bits.WarningLevel1 ) SerialIO.print("WarningLevel1 ");
    if ( status2.Bits.WarningLevel2 ) SerialIO.print("WarningLevel2 ");
    if ( status2.Bits.LowOiPowerReduction ) SerialIO.print("LowOiPowerReduction ");
    if ( status2.Bits.MaintenanceNeeded ) SerialIO.print("MaintenanceNeeded ");
    if ( status2.Bits.EngineCommError ) SerialIO.print("EngineCommError ");
    if ( status2.Bits.SubOrSecondaryThrottle ) SerialIO.print("SubOrSecondaryThrottle ");
    if ( status2.Bits.NeutralStartProtect ) SerialIO.print("NeutralStartProtect ");
    if ( status2.Bits.EngineShuttingDown ) SerialIO.print("EngineShuttingDown ");
    SerialIO.println("");

}
void CallBack(int8_t cmd) {
  switch(cmd) {
    case CMD_STATUS:
      DumpStatus();
      break;
    case CMD_BT_OFF:
      StopBluetooth();
      break;
  }
}

#ifdef WITH_LOOP_STATS
void UpdateTime(unsigned long start) {
  static double tmax = 0, tmin = 10000, tmean = 0, tstd = 0;
  static unsigned long lastOutput = 0;
  unsigned long now = millis();
  double t = now - start;
  if ( t > tmax ) tmax = t;
  if ( t < tmin ) tmin = t;
  tmean = (tmean*9/10)+t/10;
  tstd = (tstd*9/10)+((tmean-t)*(tmean-t))/10;
  if ( now-lastOutput > 10000 ) {
    lastOutput = now;
    // typically
    // Loop Stats tmax=20.000000, tmin=0.000000, tmean=2.006786, tstd=32.381637 
    Serial.printf("Loop Stats tmax=%f, tmin=%f, tmean=%f, tstd=%f\n",tmax,tmin,tmean,tstd);
  }
}
#endif



void loop() {
  // read the serial data and process.
#ifdef WITH_LOOP_STATS
  unsigned long start = millis();
#endif

  CheckBluetooth();
  engineConfig.process(CallBack);
  engineMonitor.readSensors(engineConfig.isMonitoringEnabled());
  // Send to N2K Bus
  SendRapidEngineData();
  SendEngineData();
  SendTemperatureData();
  SendVoltages();
  SendEnvironment();
  NMEA2000.ParseMessages();
  yield();
#ifdef WITH_LOOP_STATS
  UpdateTime(start);
#endif

}

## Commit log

2020-07-11 Workign version, may need some caliration tweaks
    [EngineMonitor.kicad_pcb, EngineMonitor.sch]
2020-07-13 Working version with all sensors in box ready to be installed
2020-07-13 Working version with all sensors in box ready to be installed (fixup)
2020-07-17 Redisigned board and fixed sensors
    [EngineMonitor.kicad_pcb, EngineMonitor.sch]
2020-08-26 After adjustments onboard for voltages, not very accurate due to ADC non linearity
2020-08-26 New Board, i2C ADC + CAN connection
    [EngineMonitor.kicad_pcb, EngineMonitor.sch, NMEA2000Module.kicad_pcb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]
2021-02-16 Adapted from SignalK to NMEA2000 device
    [NMEA2000Module.csv, NMEA2000Module.dsn, NMEA2000Module.sch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]
2021-02-27 Added RF code not tested, and high voltage protection diodes
    [NMEA2000Module.kicad_pcb, NMEA2000Module.sch]
2021-02-27 Fixed crash with interrupt handler not pinned into ram
2021-02-28 Tested pulse sensor and ADC operating correctly against mock engine
    [main.cpp]
2021-03-02 Added BMP280 sensor and changed to LDO regulator
    [NMEA2000Module.kicad_pcb, NMEA2000Module.sch]
2021-03-06 Calibrations on voltages
2021-03-10 Fixes after first live test
    [main.cpp]
2021-03-11 Added BT switch and engine on support
    [NMEA2000Module.kicad_pcb, NMEA2000Module.sch]
2021-03-14 Dropped oil pressure, teste fuel level
    [NMEA2000Module.sch]
2021-03-24 Added sensor simulation, fixed pressure update period
    [main.cpp]
2021-03-26 Added better support for simulation and alarms
    [NMEA2000Module.kicad_pcb, NMEA2000Module.sch]
2021-03-27 fixed engine hours, made bluetooth touch enabled, workign verison
    [main.cpp]
2021-04-02 Fixed instabilities from BT Touch enable
    [main.cpp]
2021-04-05 Update to pcb to reflect prototype
    [NMEA2000Module.kicad_pcb, NMEA2000Module.sch]
